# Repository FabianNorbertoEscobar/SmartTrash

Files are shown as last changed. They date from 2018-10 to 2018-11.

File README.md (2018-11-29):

# SMART TRASH

Proyecto SOA UNLaM 2C2018 Miércoles

## Sistemas Operativos Avanzados

### Integrantes del equipo

* Fabián Norberto Escobar ([FabianNorbertoEscobar](https://github.com/FabianNorbertoEscobar))<br>
* Ezequiel Luis Tejerina ([EzequielTejerina](https://github.com/EzequielTejerina))<br>
* Emmanuel Estigarribia ([emmanuel-estigarribia](https://github.com/emmanuel-estigarribia))<br>
* Cristian Vera ([CristianGVera](https://github.com/CristianGVera))<br>
* Martín Ferrarese ([ferrafmz](https://github.com/ferrafmz))<br>

### Sinopsis

Smart Trash es una papelera inteligente que permite arrojar papeles para mantener ordenado y limpio nuestro ambiente, ya sea en el ámbito laboral, de estudio o simplemente en el hogar, con la facilidad de no tener que abrir el tacho ni levantarse del asiento ya que este se abrirá automáticamente cuando detecte que se lo utilice. Esto nos motivó mucho ya que nos suele ocurrir que estamos ocupados realizando otras tareas y ante la necesidad de tirarlos y el tener que evaluar suspender por un momento nuestras actividades, suele optarse por no tirar los bollos de papel y simplemente ir colocándolos a un costado hasta que se forme una montaña de papel o hasta la próxima vez que tengamos que levantarnos y pasar cerca del cesto para poder arrojarlos.

Ya que esta idea ya fue implementada anteriormente, decidimos agregar algunas funcionalidades para distinguirla como información del estado de llenado del tacho con alertas de luces y sonido, y control de la luminosidad de la habitación en la que se encuentre. Además, se brinda la posibilidad de comunicación con una aplicación mobile para Android desde la cual se puede abrir y cerrar la papelera sin la necesidad de estar tan cerca del tacho para que pueda detectar que se desea usarlo. A modo de entretenimiento se ofrece la emisión de una simpática melodía como lo es la Marcha Imperial de Star Wars para distenderse por unos instantes y un modo que llamamos Tacho Loco en que la tapa abre y cierra el tacho rápidamente y de forma indeterminada, y también se puede cambiar a amarillo la luz del led RGB.

## Hardware utilizado
    
### Sistema embebido Arduino
1 placa de prototipado Arduino Uno<br>
1 cable USB puerto serial Arduino Uno 30cm<br>
1 mini Protoboard 830 puntos<br>
1 kit de jumpers con sockets<br>
1 tira de headers macho-macho<br>
6 resistores de 220Ω 5%<br>
1 resistor de 1KΩ 5%<br>
1 módulo Bluetooth HC06<br>
1 LED rojo 5mm<br>
1 LED verde 5mm<br>
1 LED azul 5mm<br>
1 módulo LED RGB<br>
1 pulsador Tact Switch 6mm x 6mm x 5mm<br>
1 micro servo motor Tower Pro Sg90 1.2kg<br>
1 Piezo Buzzer activo 5v<br>
1 fotorresistor Ldr 5mm<br>
2 sensor PIR HC Sr501<br>
1 sensor IR Pcb A0106<br>
1 papelera<br>
1 fuente transformador 9v 1a<br>

### Aplicación Android
Smartphones con sistema operativo Android (para probar la app)<br>
Sensor de proximidad<br>
Acelerómetro<br>
Giroscopio<br>

## Software utilizado

IDE Arduino Genuino 1.8.7 (para el desarrollo del sistema embebido para la placa Arduino Uno)<br>
IDE Android Studio 3.2.1 (para el desarrollo de la aplicación mobile para Android)<br>
Android SDK 28.0.1 (software development kit para Android)<br>
ISO Android 4.0.3 Ice Cream Sandwich (para la simulación de la aplicación mobile para Android)<br>
Tinkercad Autodesk 2018 (para la simulación previa implementación del sistema embebido Arduino)<br>

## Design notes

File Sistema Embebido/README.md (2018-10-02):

# SMART TRASH

Sistema Embebido Arduino

## Sistemas Operativos Avanzados

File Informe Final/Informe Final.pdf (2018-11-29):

### Universidad Nacional de La Matanza

### Departamento de Ingeniería e Investigaciones Tecnológicas Ingeniería en Informática

### Sistemas Operativos Avanzados

### Sistemas Embebidos - Arduino y Android

## “Smart Trash”

Segundo Cuatrimestre 2018 - Año 2018

Docentes:
- Lic. Graciela de Luca
- Ing. Waldo Valiente
- Ing. Esteban Carnuccio
- Ing. Mariano Volker
- Ing. Sebastián Barillaro
- Ing. Gerardo Garcia

Integrantes:
- ESCOBAR, Fabián Norberto | DNI 39210915
- ESTIGARRIBIA, Emmanuel | DNI 38531035
- FERRARESE, Martín | DNI 36073729
- TEJERINA, Ezequiel Luis | DNI 39268074
- VERA, Cristian | DNI 33786091

Sistemas Operativos Avanzados | Smart Trash

### Índice

Introducción | 2
Descripción general del sistema | 2
Alcance del sistema | 3
Sistema embebido Arduino | 3
Aplicación Android | 4
Componentes | 4
Software utilizado | 4
Hardware utilizado | 4
Sistema embebido Arduino | 4
Aplicación Android | 5
Circuito | 5
Implementación | 6
Sistema embebido Android | 6
Módulo Bluetooth | 6
PIR | 6
IR | 7
Fotorresistor | 7
Pulsador | 7
Piezo Buzzer | 7
LED | 8
RGB LED | 8
Micro Servo Motor | 8
Aplicación Android | 8
Activities | 8
Sensores | 12
Modo de uso | 13
Descripción de componentes | 14
Arduino Uno | 14
Fuente de alimentación | 15
Módulo Bluetooth HC05 | 16
Sensor PIR | 16
Sensor IR | 17
Fotoresistor | 18
Pulsador | 18
Piezo Buzzer | 18
LED | 19
RGB LED | 19
Micro Servo Motor | 20
Diagramas | 21
Diagrama físico | 21
Diagrama lógico | 22
Diagrama funcional | 23
Diagrama de hardware | 24
Diagrama de software | 26
Imágenes del prototipo | 27
Problemas presentados y mejoras a futuro | 31

### Introducción

A lo largo de este informe se explica nuestro proyecto para Sistemas Operativos Avanzados, en el que pudimos experimentar en el mundo de los sistemas embebidos y de las aplicaciones mobile. Nos vimos obligados a alejarnos un poco de lo que veníamos acostumbrados a trabajar, es decir, solo software, para poder dedicarnos también al hardware. Llevamos a cabo el desarrollo completo de un proyecto constituido por dos sistemas desde el surgimiento de una idea que nos motive, el planeamiento, el modelado, la adquisición de los componentes necesarios y el entrenamiento para poder trabajar con aquello que no conocíamos, hasta la puesta en marcha de la idea, la simulación del sistema embebido, la prueba de cada componente, su disposición y su conexión, el armado de la estructura, el desarrollo de los sistemas de software, la comunicación entre ellos y el testeo para comprobar que todo funcione adecuadamente.

Primero se describe en detalle la idea y la motivación por la que la hemos elegido, el objetivo de cada uno de los sistemas y todo lo que abarcan. Luego, contamos cuáles son los componentes que se usaron, mostramos un diagrama del circuito con la conexión dispuesta, aclaramos el uso que se le da a cada uno y adjuntamos una descripción técnica y del funcionamiento de cada elemento. Finalmente, se muestran los diagramas usados para el modelado, se cuentan cuáles son los problemas con los que nos hemos topado y se deja una propuesta de mejora a futuro.

### Descripción general del sistema

Smart Trash es una idea que surge de nuestras ganas de desarrollar un producto que brinde comodidades a las personas. Entre otras ideas, esta fue la que prevaleció ya que fue la que más nos gustó e interesó concretar.

Smart Trash es una papelera inteligente que permite arrojar papeles para mantener ordenado y limpio nuestro ambiente, ya sea en el ámbito laboral, de estudio o simplemente en el hogar, con la facilidad de no tener que abrir el tacho ni levantarse del asiento ya que este se abrirá automáticamente cuando detecte que se lo utilice. Esto nos motivó mucho ya que nos suele ocurrir que estamos ocupados realizando otras tareas y ante la necesidad de tirarlos y el tener que evaluar suspender por un momento nuestras actividades, suele optarse por no tirar los bollos de papel y simplemente ir colocándolos a un costado hasta que se forme una montaña de papel o hasta la próxima vez que tengamos que levantarnos y pasar cerca del cesto para poder arrojarlos.

Ya que esta idea ya fue implementada anteriormente, decidimos agregar algunas funcionalidades para distinguirla como información del estado de llenado del tacho con alertas de luces y sonido, y control de la luminosidad de la habitación en la que se encuentre. Además, se brinda la posibilidad de comunicación con una aplicación mobile para Android desde la cual se puede abrir y cerrar la papelera sin la necesidad de estar tan cerca del tacho para que pueda detectar que se desea usarlo. A modo de entretenimiento, se ofrece la emisión de una simpática melodía como lo es la Marcha Imperial de Star Wars para distenderse por unos instantes, un modo que llamamos Tacho Loco en que la tapa abre y cierra el tacho rápidamente y de forma indeterminada, y también se puede cambiar a amarillo el color del led RGB.

Para su uso, usted debe conectar la papelera a la red eléctrica mediante la ficha de su transformador, o también alimentarlo por cable USB y colocarlo en un lugar que le sea cómodo y que quede de frente al lugar en el que se encuentre para que detecte cuando requiera que se abra. No debe colocar nada sobre la tapa del producto que impida que se abra cuando corresponda incluso atentando contra su integridad. Además, debe contar con un smartphone con sistema operativo Android y por supuesto instalar la aplicación de Smart Trash, para poder usarla cuando usted quiera. Cabe aclarar que debe tener encendido el Bluetooth del dispositivo, de lo contrario, se le pedirá que lo encienda.

### Alcance del sistema

Sistema embebido Arduino

El sistema embebido Arduino es el que provee el funcionamiento de la papelera inteligente. Este sistema reside en la placa de prototipado Arduino con la que cuenta el cesto, la que se encuentra detrás de la papelera, dentro de la cajita.

El tacho enciende los LEDs que se encuentran en su frente dando información acerca del nivel de llenado: el LED verde está encendido mientras el tacho no está lleno, es decir, está vacío o aún tiene lugar disponible, y el LED rojo está encendido cuando el tacho está lleno; ambos LEDs se mantienen encendidos durante el vaciado; el LED azul se enciende cuando el tacho está en modo Bluetooth para ser manejado desde la aplicación Android. El LED transparente se apaga o enciende mostrando diferentes colores de acuerdo a la situación, diferenciando cuando en el ambiente hay mucha luz o poca luz, o cuando se está emitiendo la marcha imperial, o cuando se indica un cambio de color desde la aplicación.

Cuando se agita el celular, la tapa se levanta para que se pueda arrojar un bollo de papel y se baja cuando se vuelve a agitar. Cuando se activa el sensor de proximidad del celular, se inicia el modo Tacho Loco, abriendo y cerrando el tacho sin parar. Y la tapa se mantiene levantada cuando se ordena el vaciado del tacho al ser presionado el pulsador amarillo que se encuentra en el perfil derecho o cuando se indica desde la aplicación.

Adelante y sobre la tapa de la papelera, se encuentran los sensores de proximidad que controlan el comportamiento de la tapa. Adentro, está colocado el sensor IR que se encarga de controlar si el tacho se llena. En el perfil izquierdo, se encuentra el buzzer que emite la marcha imperial y el sonido de alerta indicando que el tacho está lleno. El buzzer también emite un sonido tras ser alimentado para indicar que está disponible para ser utilizado. Por último, en la arista delantera izquierda se encuentra el sensor que capta la luminosidad.

Aplicación Android

La aplicación mobile para Android es el sistema que provee la comunicación del smartphone con la papelera inteligente, la que se establece mediante conexión vía Bluetooth. La app tiene una interfaz muy sencilla para facilidad del usuario. Primero que nada muestra los dispositivos Bluetooth emparejados y ofrece agregar y quitar conexiones. Permite abrir y cerrar el tacho como alternativa a la detección de proximidad, así como permite cambiar el color que se emite en el led RGB, habilitar la marcha imperial y el tacho loco. Hace uso de tres sensores del framework de Android: sensor de proximidad, acelerómetro y giróscopo. En base a sus mediciones, ofrece comandos según si el smartphone es agitado, si es colocado de costado o si su sensor frontal detecta proximidad.

### Componentes

Software utilizado

- IDE Arduino Genuino 1.8.7 (para el desarrollo del sistema embebido para la placa Arduino Uno)
- IDE Android Studio 3.2.1 (para el desarrollo de la aplicación mobile para Android).
- Android SDK 28.0.1 (software development kit para Android)
- ISO Android 4.0.3 Ice Cream Sandwich (para la simulación de la aplicación mobile para Android)
- Tinkercad Autodesk 2018 (para la simulación previa implementación del sistema embebido Arduino)

Hardware utilizado

- Sistema embebido Arduino
- 1 placa de prototipado Arduino Uno
- 1 cable USB puerto serial Arduino Uno 30cm
- 1 mini Protoboard 830 puntos
- 1 kit de jumpers con sockets
- 1 tira de headers macho-macho
- 6 resistores de 220Ω 5%
- 1 resistor de 1KΩ 5%
- 1 módulo Bluetooth HC06
- 1 LED rojo 5mm
- 1 LED verde 5mm
- 1 LED azul 5mm
- 1 módulo LED RGB
- 1 pulsador Tact Switch 6mm x 6mm x 5mm
- 1 micro servo motor Tower Pro Sg90 1.2kg
- 1 Piezo Buzzer activo 5v

- 1 fotorresistor Ldr 5mm
- 2 sensor PIR HC Sr501
- 1 sensor IR Pcb A0106
- 1 papelera
- 1 fuente transformador 9v 1a
- Aplicación Android
- Smartphones con sistema operativo Android (para usar la app)
- Sensor de proximidad
- Acelerómetro
- Giroscopio

### Circuito

El circuito fue diseñado y simulado desde el comienzo usando la aplicación online Tinkercad de Autodesk para asegurarnos de cómo se conectan los componentes y que de esa forma funcionan correctamente. También lo usamos como precaución para no correr el riesgo de quemar ningún elemento y en un principio entrenamos aquí para empezar a entrar en contacto con el mundo Arduino.

El proyecto puede encontrarse en https://www.tinkercad.com/things/dwYeEtnybhy, donde puede ser simulado y copiado para ser modificado si alguien lo desea. Allí también puede verse el código con el que fue programado. El circuito simulado se muestra en la siguiente imagen:

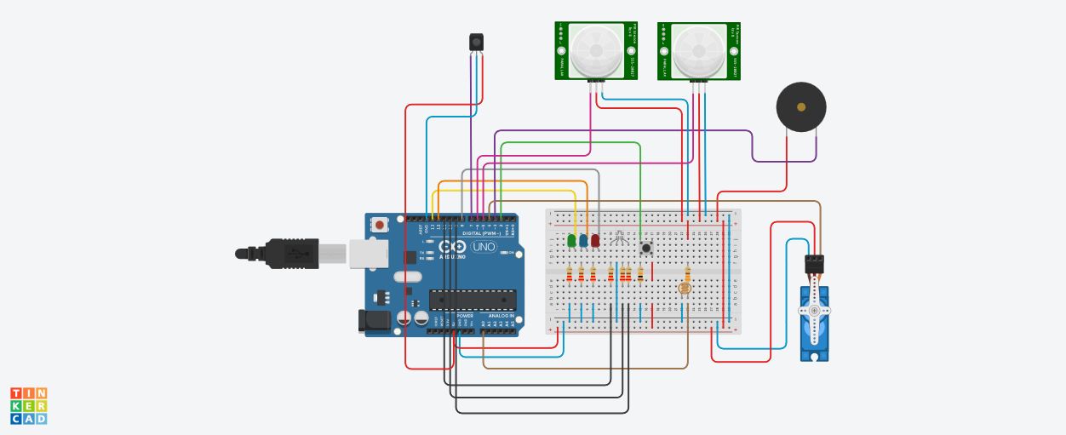
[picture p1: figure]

La única diferencia con la realidad es el uso del módulo Bluetooth el cual no está disponible en este simulador y por lo tanto no pudimos incluir en el diagrama del circuito. El mismo tiene pines positivo y negativo, y dos pines de señal que están conectados a las entradas digitales 0 y 1. El pin Rx del módulo Bluetooth está conectado al pin Tx de la placa Arduino y el pin Tx del módulo Bluetooth está conectado al pin Rx de la placa Arduino.

### Implementación

Sistema embebido - Android

- Módulo Bluetooth

Haciendo uso de la librería “SoftwareSerial.h”, desarrollamos la comunicación del módulo Bluetooth integrado en el Arduino con la aplicación Android. Es una pieza clave en el producto, ya que, a partir de dicha comunicación, se comparten datos que, en base a qué valores tengan, se realizarán distintas acciones (tanto en el sistema embebido Arduino como en la aplicación Android).

Se utilizan las siguientes funciones:
- SoftwareSerial: crea una nueva instancia del objeto SoftwareSerial.
- available: obtiene el número de bytes disponibles para la lectura de un puerto serie software.
- begin: se configura la velocidad en baudios para la comunicación serie.
- read: devuelve un carácter que se recibió en el pin RX del puerto serie de software.
- write: envía los comandos al dispositivo Android.

Básicamente, los datos enviados por la aplicación Android, indican:
- apertura y cierre del tacho.
- modo marcha: emisión de la marcha imperial.
- modo tacho loco: el tacho se abre y cierra.
- cambio de color del led RGB: apagado y color alternativo.
- PIR

Para su implementación, lo único que hicimos es obtener los valores del sensor a través de la función digitalRead. Se le debe configurar la sensibilidad tanto de distancia como de tiempo. Lo configuramos para que tenga un buen alcance para brindar más comodidades a las personas que lo usen.

El sensor PIR viene con un lente de Fresnel que tiene el objetivo de permitir una mayor sensibilidad, pero también amplía el ángulo de detección, por lo que decidimos cubrir parcialmente el lente para que sense solo el rango que nos interese. Uno de los sensores PIR está colocado en el frente del tacho para detectar movimiento adelante y el otro sensor se encuentra en la tapa para que detecte movimiento arriba del tacho.

Si los sensores detectan movimiento, la papelera se abre, y si los sensores no detectan movimiento, la papelera se cierra.

- IR

Para su implementación, de la misma forma que con los sensores PIR, lo único que hicimos es obtener los valores del sensor a través de la función digitalRead. Este sensor se encuentra ubicado dentro del tacho, apuntando desde la cara trasera hacia la cara delantera para cubrir la apertura. Si el sensor detecta una obstrucción dada por un objeto, en este caso papel, entonces se comprende que el tacho está lleno.

- Fotorresistor

El fotorresistor es usado para detectar el nivel de luz que hay en el ambiente y para eso se obtiene el valor de su lectura a través de la función digitalRead. Este sensor se encuentra ubicado en la arista izquierda del frente de la papelera, posición estratégica pensando que el tacho seguramente esté colocado de espaldas a una pared. Allí, la luz va a ser detectada sin inconvenientes.

- Pulsador

El pulsador se utiliza para indicar el vaciamiento del tacho. Para esto, se hace uso de la función digitalRead. Cuando se detecta que fue presionado, de activa el vaciamiento del tacho, por lo que la tapa se queda abierta hasta que se termine de quitar los papeles del interior. Cuando deja de estar presionado el pulsador, la tapa se baja. El pulsador está ubicado en el perfil derecho.

- Piezo Buzzer

El Piezo Buzzer se usa para la emisión de los sonidos. Para reproducir los tonos, se usa la función tone, a la que se indica la frecuencia y la duración del tono, y para no reproducir un tono se usa la función noTone. El speaker se encuentra en el perfil izquierdo.

Por una parte, reproduce la alarma que indica que la papelera está llena, la que consta de dos pitidos que se repetirán hasta que no se vacíe el tacho. Por otra parte, reproduce la marcha imperial de Star Wars, la melodía que elegimos para la funcionalidad de entretenimiento. La marcha imperial está formada por una cantidad mayor de tonos con diversidad de frecuencias y duraciones. Además, se usa para emitir un sonido una vez que el dispositivo está listo para usarse tras haber sido conectado.

Para la correcta formación de la canción de la marcha imperial, es necesaria la utilización de la función delay provista por Arduino para la implementación de las pausas. Y si bien es desalentado su uso debido al parate que implica en el desarrollo de tareas, no queda más que usarla porque de lo contrario la marcha no se puede emitir adecuadamente.

- LED

Los leds son uno de los elementos más sencillos de utilizar ya que se encienden y apagan con la función digitalWrite, variando el parámetro de estado entre HIGH y LOW, según corresponda. Todos los leds se encuentran en el frente de la papelera, en la esquina superior derecha.

El led rojo se enciende cuando el tacho está lleno, el led verde se enciende cuando el tacho está vacío o no está vacío pero aún tiene lugar, ambos están encendidos durante el vaciado y el led azul se enciende cuando el modo Bluetooth está activado.

- RGB LED

Este led RGB tiene un uso similar al de un led común, pero para la formación de un color se da un valor a cada componente con la función digitalWrite, como si se estuviese manejando a tres leds diferentes.

Este led se encuentra en el frente de la papelera, en la esquina superior izquierda. Le asignamos varios usos a este led. Toma distintos colores o se apaga según la ocasión, variando en las siguientes: mucha luz en el ambiente, poca luz en el ambiente, alarma por tacho lleno, marcha Imperial y cambio de color.

- Micro Servo Motor

El servomotor tiene una implementación sencilla. Simplemente se maneja con la función write con la que se indica el ángulo de posición en el que se debe colocar el servo. Está colocado sobre el borde izquierdo del perfil izquierdo del tacho, pegado a la bisagra de la tapa. Solamente se usan dos posiciones: 180 grados para poner el tacho en abierto y 90 grados para poner el tacho en cerrado.

Además interviene obviamente en el modo tacho loco en el que se mueve la tapa sin parar. Para que la apertura y cierre tenga tiempo de realizarse completa, fue necesario el uso de la función delay para generar un retraso

Aplicación Android

- Activities

A continuación, se muestran las activities que forman la aplicación:

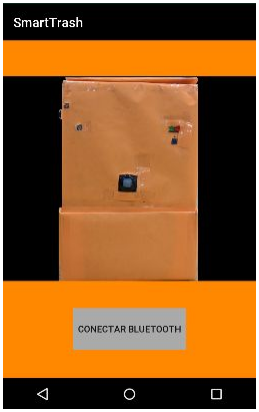
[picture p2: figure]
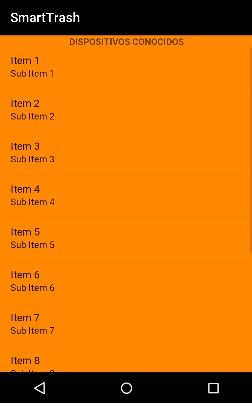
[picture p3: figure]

- Sensores
- Giróscopo

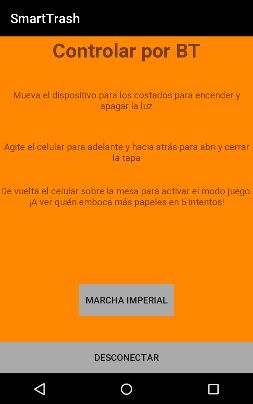
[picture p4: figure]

El giróscopo, giroscopio o gyro, como se conoce en inglés, mide la velocidad de rotación del dispositivo alrededor de los ejes x , y, y z, y sus propiedades se resumen en esta tabla:

Este sensor lo usamos de la siguiente manera:
- cuando se detecta que el smartphone es girado hacia la izquierda, se envía un comando al sistema embebido Arduino para que se encienda el led RGB en su combinación amarilla;

- cuando se detecta que el smartphone es girado hacia la derecha, se envía un comando al sistema embebido Arduino para que se cambie el color del led rgb.
- Acelerómetro

El sensor TYPE_ACCELEROMETER mide la aceleración aplicada al dispositivo y sus propiedades se resumen en esta tabla:

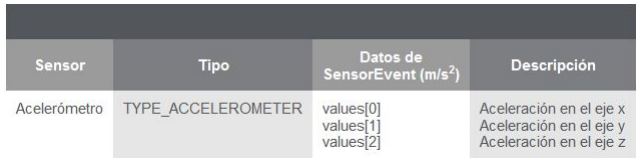
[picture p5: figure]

Este sensor lo usamos de la siguiente manera:
- cuando se detecta que el smartphone es agitado hacia adelante y hacia atrás, se envía un comando al sistema embebido Arduino para que se abra o cierre la papelera, según corresponda, de acuerdo al estado en el que se encuentra la tapa en ese instante.
- Sensor de proximidad

El sensor TYPE_PROXIMITY proporciona la distancia entre el dispositivo y otro objeto y puede por ejemplo usarse para determinar si la persona lo sostiene cerca de su cara al hacer una llamada o simplemente pasa su mano cerca de él; y sus propiedades se resumen en esta tabla:

Este sensor lo usamos de la siguiente manera:
- cuando se detecta que el sensor de proximidad del smartphone está tapado, se envía un comando al sistema embebido Arduino para activar modo juego, el cual abre y cierra la tapa automáticamente unas 5 veces.
- Modo de uso

Es muy sencillo utilizar la app, básicamente pueden realizarse las siguientes:
- previamente, se debe emparejar la papelera con el dispositivo Android por medio de los ajustes del propio sistema.
- abrir la aplicación SmartTrash.
- presionar el botón “Conectar Bluetooth” para ver las papeleras emparejadas.
- presionar la papelera emparejada a la que se desee controlar.
- realizar alguna de las acciones allí mencionada. ¡Hay muchas opciones!
- presionar el botón desconectar la papelera cuando quiera finalizar su uso.

### Descripción de los componentes

- Arduino Uno

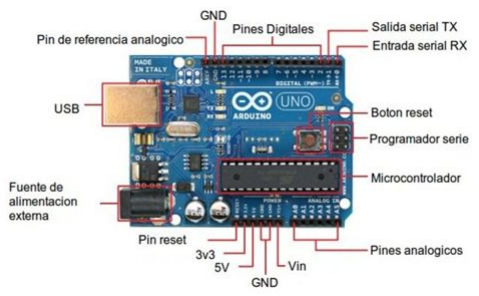
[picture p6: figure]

Arduino es una plataforma de creación de electrónica de código abierto, la cual está basada en hardware y software libre, flexible y fácil de utilizar para los creadores y desarrolladores. Esta plataforma permite crear diferentes tipos de sistemas embebidos a los que la comunidad de creadores puede darles diferentes tipos de uso. Esto es, en gran parte, gracias a la alta compatibilidad con un vasto conjunto de sensores y actuadores de los más variados tipos.

En particular, en nuestro proyecto usamos la placa Arduino UNO R3, la cual es la más documentada de toda la familia de placas Arduino, según la propia página web oficial de Arduino. Esta, al igual que la mayoría, puede ser alimentada de varias formas, con un cable USB conectado al ordenador o con una fuente externa. El lenguaje de programación del microcontrolador está basado en C y C++.

Características técnicas:

Microcontrolador | ATmega328P
Tensión de funcionamiento | 5V
Voltaje de entrada (recomendado) | 7-12V
Voltaje de entrada (límite) | 6-20V
Digital pines I/O | 14 (de los cuales 6 proporcionan una salida PWM)

PWM digital pines I/O | 6
Pines de entrada analógica | 6
Corriente DC por Pin I/O | 20mA
Corriente DC para Pin 3.3V | 60mA
Memoria flash | 32KB ATmega328P de los que 0,5 KB son utilizados por el gestor de arranque.
SRAM | 2KB ATmega328P
EEPROM | 1KB ATmega328P
Velocidad de reloj | 16 MHz
Longitud | 68,6 mm
Anchura | 53,4 mm
Peso | 25 g
- Fuente de alimentación

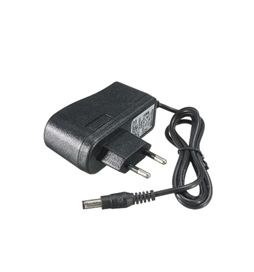
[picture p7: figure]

La fuente de alimentación es el dispositivo que convierte la corriente alterna, en una o varias corrientes continuas, que alimentan los distintos circuitos del aparato electrónico al que se conecta.

En nuestro caso, usamos una fuente de 9v, para alimentar la placa Arduino, junto con los sensores, actuadores, y el módulo bluetooth, para hacer al embebido independiente de tener que estar siempre conectado a una computadora y
poderlo | alimentar | directamente | con | un
tomacorrientes convencional.

- Módulo Bluetooth HC-05

Es el módulo que usamos para conectar el sistema embebido a un celular inalámbricamente. Se configura mediante comandos AT y tiene la posibilidad de hacerlo funcionar tanto en modo maestro como esclavo. Esto quiere decir que además de recibir conexiones desde una PC o celular, también es capaz de generar conexiones hacia otros dispositivos bluetooth.

El módulo Bluetooth HC-05 puede alimentarse
con una tensión de entre 3.3 y 6V (normalmente 5V),
pero los pines TX y RX utilizan niveles de 3,3V por lo

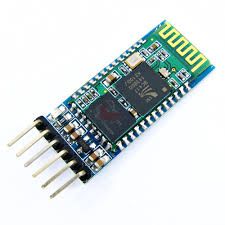
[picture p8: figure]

que no se puede conectar directamente a placas de 5V, sino que hay que usar resistencias para limitar la misma.

- Sensor PIR HC-SR501

Los detectores PIR (Passive Infrared
Receiver) | o | receptor | pasivo | Infrarrojo,
reaccionan ante el calor del cuerpo humano o animales. Estos captan la presencia detectando la diferencia entre el calor emitido por el cuerpo humano y el espacio alrededor. Son llamados pasivos debido a que no emiten radiaciones, sino que solamente las reciben.

Su componente principal son los sensores piroeléctricos. Se trata de un componente electrónico diseñado para detectar cambios en la radiación infrarroja recibida. Generalmente dentro de su encapsulado

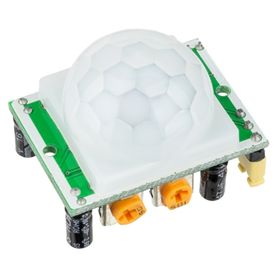
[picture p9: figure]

incorporan un transistor de efecto de campo que amplifica la señal eléctrica que genera cuando se produce dicha variación de radiación recibida. El sensor está dividido en dos mitades. La razón de ello es que se desea detectar movimiento (cambio) y no los niveles promedio de IR. Las dos mitades están cableados de manera que se anulan entre sí. Si uno ve la mitad con más o menos radiación IR que el otro, la salida se moverá a alta o baja.

Además, cuenta con un lente de Fresnel, el cual es un encapsulado semiesférico hecho de polietileno de alta densidad cuyo objetivo es permitir el paso de la radiación infrarroja y concentrar la energía en la superficie de detección del sensor, permitiendo una mayor sensibilidad del dispositivo.

El HC-SR501 permite ajustar el tiempo de disparo de la señal de alarma de movimiento, con un mínimo de 3 seg y un máximo de 5 min. Así mismo, se puede ajustar la distancia de detección, con un mínimo de 3 mts y un máximo de 7 mts.

Especificaciones técnicas:

Voltaje de alimentación | 5 a 12
Consumo promedio | Menor a 1mA
Distancia de detección | 3 a 7 metros
Ángulo de detección | Cono de 110°
Tiempo de inicialización | 1 minuto antes de que inicie su operación normal
Temperatura de operación | -15° a +70° C
- Sensor IR

Formado por un emisor y un receptor IR, es lo que usamos para detectar si el tacho está lleno.

El emisor es un led, que funciona con una longitud de onda de 940nm. Mientras que el receptor es un fotodiodo, un dispositivo que conduce una cantidad de corriente eléctrica proporcional a la cantidad de luz que lo ilumina o incide.

En la implementación establecimos un nivel (la altura donde ubicamos el sensor), y evaluamos si la recepción se corta o no. Este mecanismo nos

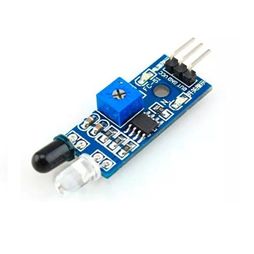
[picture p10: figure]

sirve para contar la cantidad de veces que se tira algo dentro de la papelera, además de la función de detectar si está llena (por haber alcanzado la altura del sensor).

- Fotoresistor (LDR)

El LDR (Light-Dependent Resistor, resistor dependiente de la luz) es un resistor que varía su valor de resistencia eléctrica dependiendo de la cantidad de luz que incide sobre él. Se le llama, también, fotorresistor o fotorresistencia. El valor de resistencia eléctrica de un LDR es bajo cuando hay luz incidiendo en él (en algunos casos puede descender a tan bajo como 50 ohms) y muy alto
cuando está a oscuras (puede ser de varios
megaohms).

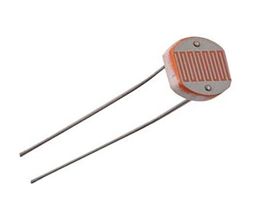
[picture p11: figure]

El uso que le dimos en nuestro proyecto es detectar el nivel de iluminación del ambiente, para prender el led RGB y hacer a la papelera más sencilla de ubicar. Además de poder controlarse desde la aplicación en Android.

- Pulsador

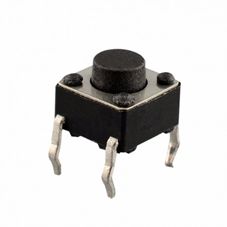
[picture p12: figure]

Un pulsador es básicamente un interruptor con dos estados, presionado o libre. Cuando se presiona, dentro del interruptor, dos cables son unidos, lo que permite a la corriente fluir y envía un estado HIGH a la placa. Cuando se libera, los dos cables son desunidos y corta el flujo de la corriente, significando una estado LOW de señal.

Usamos un pulsador en el proyecto para poder abrir la papelera cuando esta queda bloqueada (al detectar que se llenó), y cerrarla nuevamente para volver a activar los sensores.

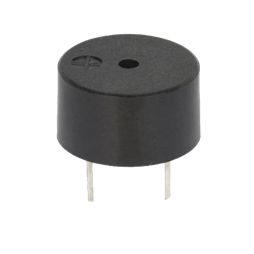
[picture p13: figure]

- Piezo Buzzer

Un buzzer, en español también llamado zumbador, es un transductor electroacústico que produce un sonido o zumbido continuo o intermitente de un mismo tono.

La piezoelectricidad (de ahí el nombre de piezo buzzer) es un fenómeno que ocurre en determinados cristales que, al ser sometidos a tensiones mecánicas, adquieren una polarización eléctrica y aparece una diferencia de potencial y cargas eléctricas en su superficie que generan una tensión eléctrica. Es decir, que son materiales que al someterlos a una tensión eléctrica variable (como una señal PWM) vibran.

Utilizamos el buzzer con diversas funciones, desde alertar que la papelera está llena o que ya ha sido inicializada para usarse, hasta reproducir una melodía en el modo marcha imperial

- LEDs

Un diodo emisor de luz
(también conocido por la sigla LED, del inglés light-emitting diode) es una fuente de luz constituida por un material semiconductor dotado de dos terminales. Se trata de un diodo de unión p-n, que emite luz cuando está activado. Si se aplica una tensión adecuada a los terminales, los electrones se recombinan con los huecos en la región de la unión p-n del dispositivo, liberando energía en forma de fotones.

Usamos 3 leds: rojo, verde y azul. El rojo para indicar que la papelera está llena, el verde para indicar que sigue teniendo espacio, y el azul para indicar conexión con un dispositivo mediante bluetooth.

- LED RGB

Es un tipo de led especial, el cual permite crear combinaciones de los colores primarios en la iluminación (rojo, verde y azul), para mostrar muchos más colores.

Para eso, en el código se envían valores entre 0 y 255 para cada componente de color, representando la intensidad de estos, formando así una gran variedad de colores secundarios y terciarios.

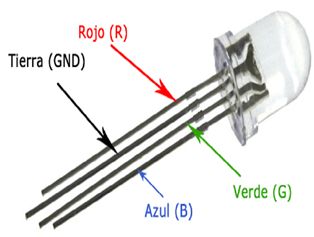
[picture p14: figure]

En nuestro proyecto, el led RGB es usado para dar iluminación a la papelera en caso de baja iluminación del entorno, y para acompañar el modo marcha imperial.

- Micro Servomotor SG-90

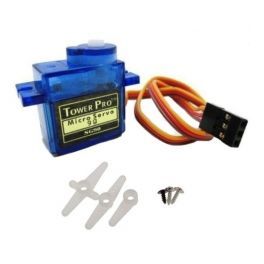
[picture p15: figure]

Un servomotor (también llamado servo) es un dispositivo similar a un motor de corriente continua que tiene la capacidad de ubicarse en cualquier posición dentro de su rango de operación, y mantenerse estable en dicha posición. Tiene incorporado un sistema de regulación que puede ser controlado tanto en velocidad como en posición.

El micro servo SG-90 tiene requerimientos de energía bastante bajos lo que permite alimentarlo con la misma fuente de alimentación que el resto del circuito.

Características técnicas:

Velocidad | 0.10 sec/60° @ 4.8V
Torque | 1.8 Kg-cm @ 4.8V
Voltaje de funcionamiento | 3.0-7.2V
Temperatura de funcionamiento | -30 ℃ a 60 ℃
Ángulo de rotación | 180°
Ancho de pulso | 500-2400 µs

En nuestro proyecto, el micro servo es el que mueve la tapa de la papelera, en función de lo que detecten los sensores, o del comando que el embebido reciba del celular.

### Diagramas

- Diagrama físico

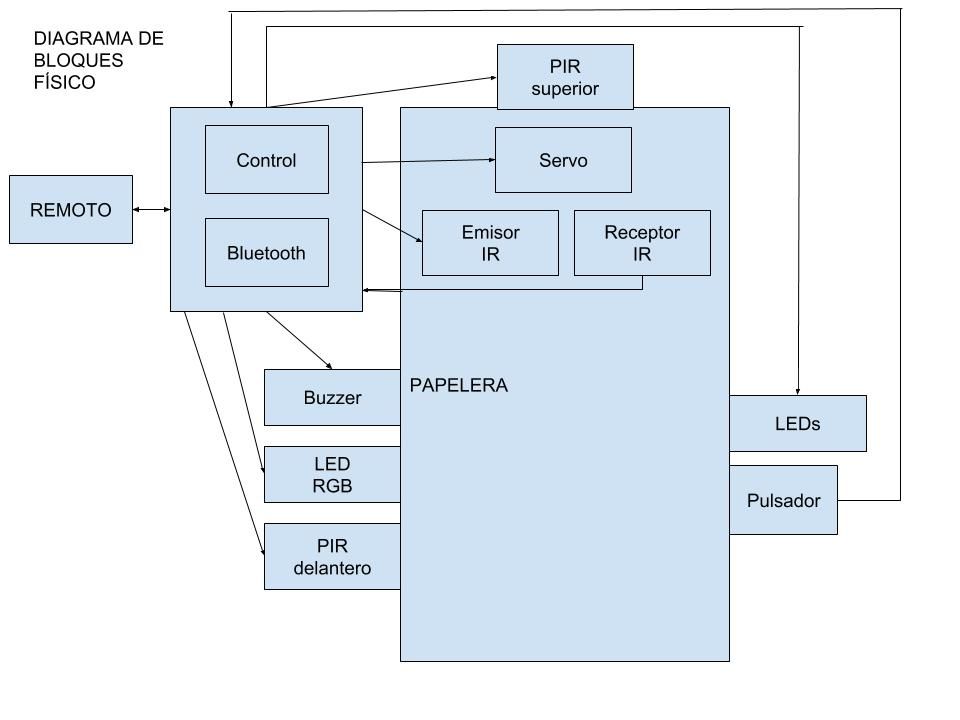
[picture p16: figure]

- Diagrama lógico

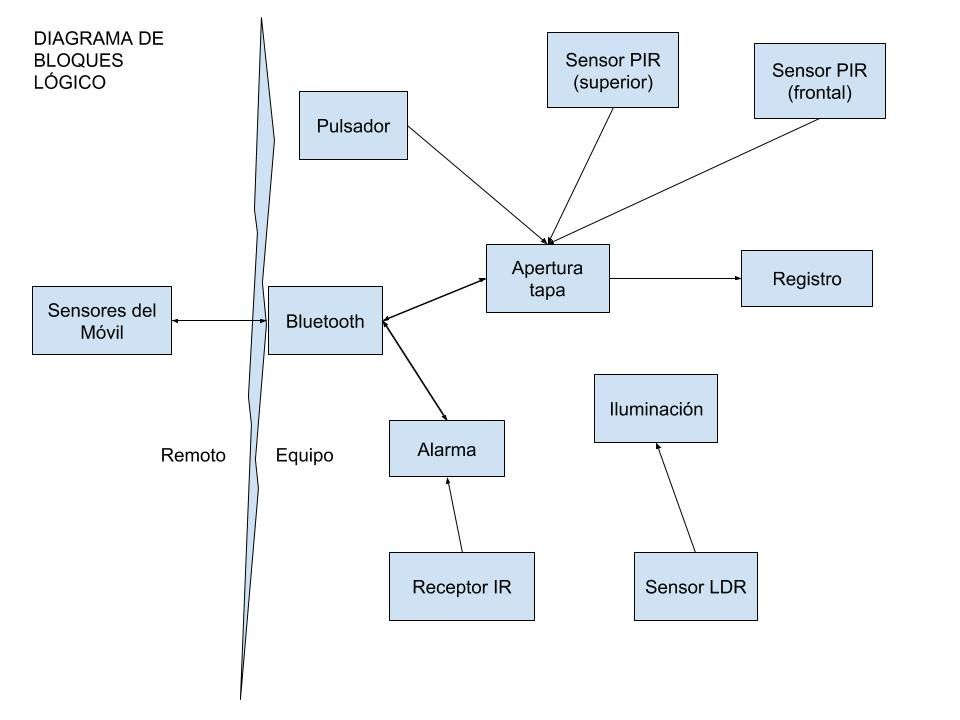
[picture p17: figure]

- Diagrama funcional

- Diagrama de hardware

Vista frontal

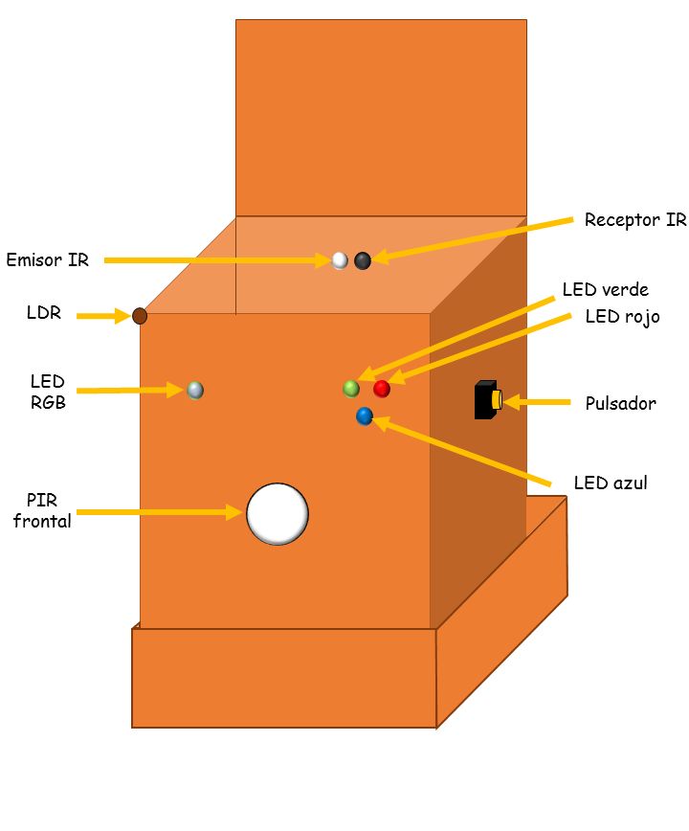
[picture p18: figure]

Vista trasera

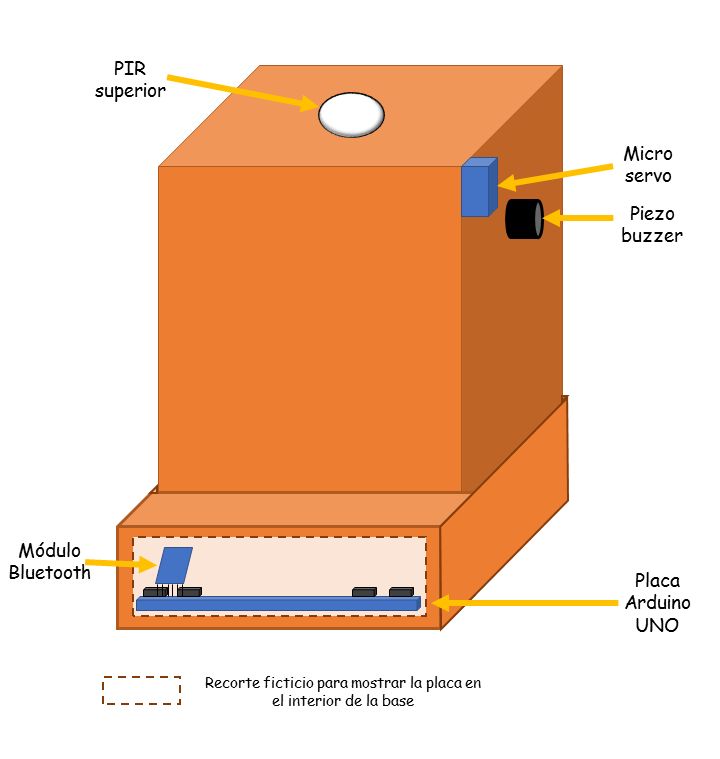
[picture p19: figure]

- Diagrama de software

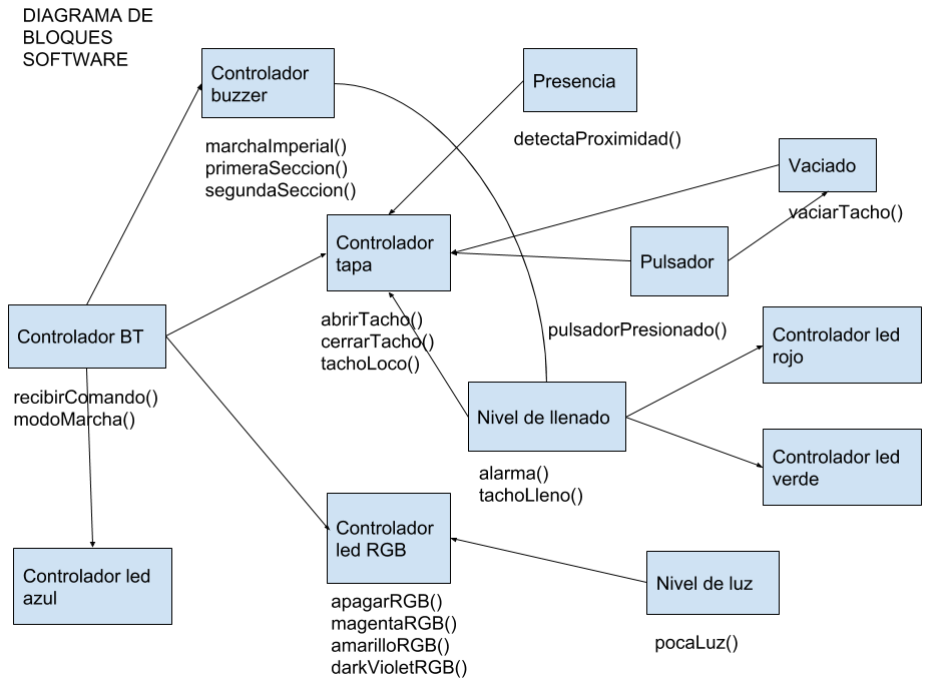
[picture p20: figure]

### Imágenes del prototipo

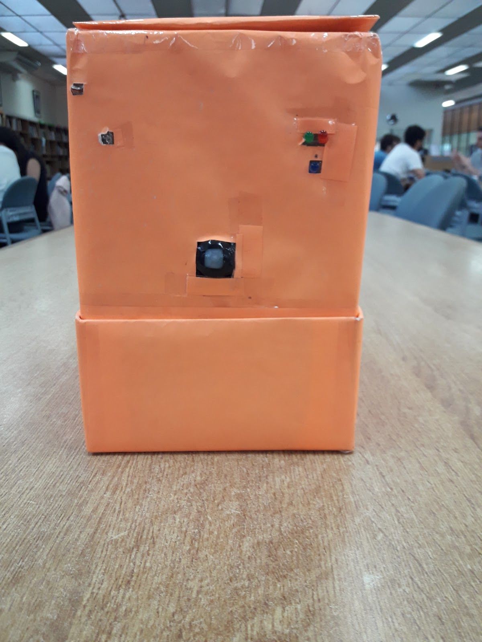
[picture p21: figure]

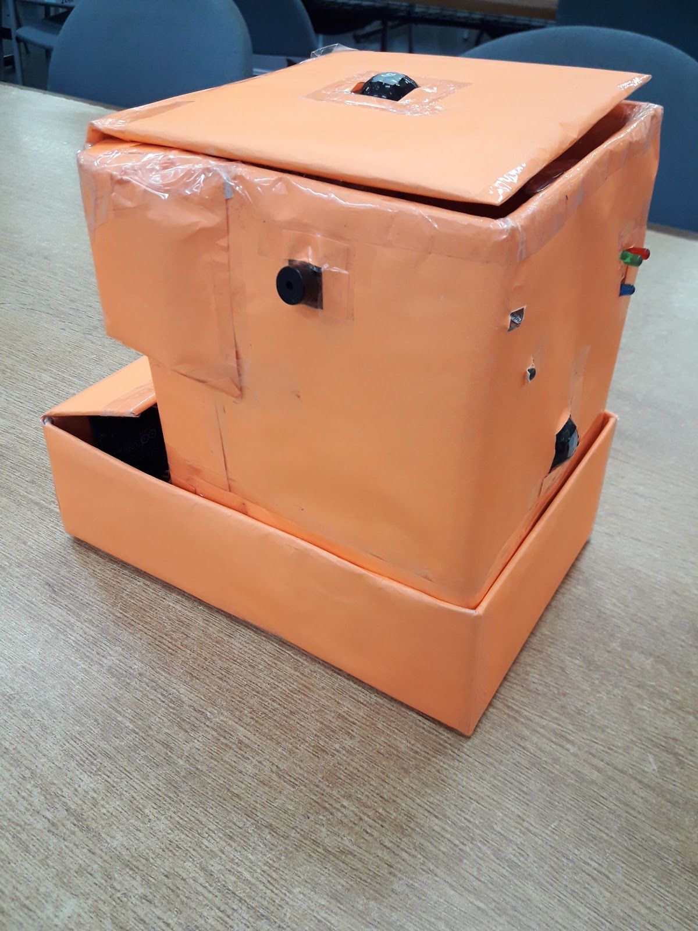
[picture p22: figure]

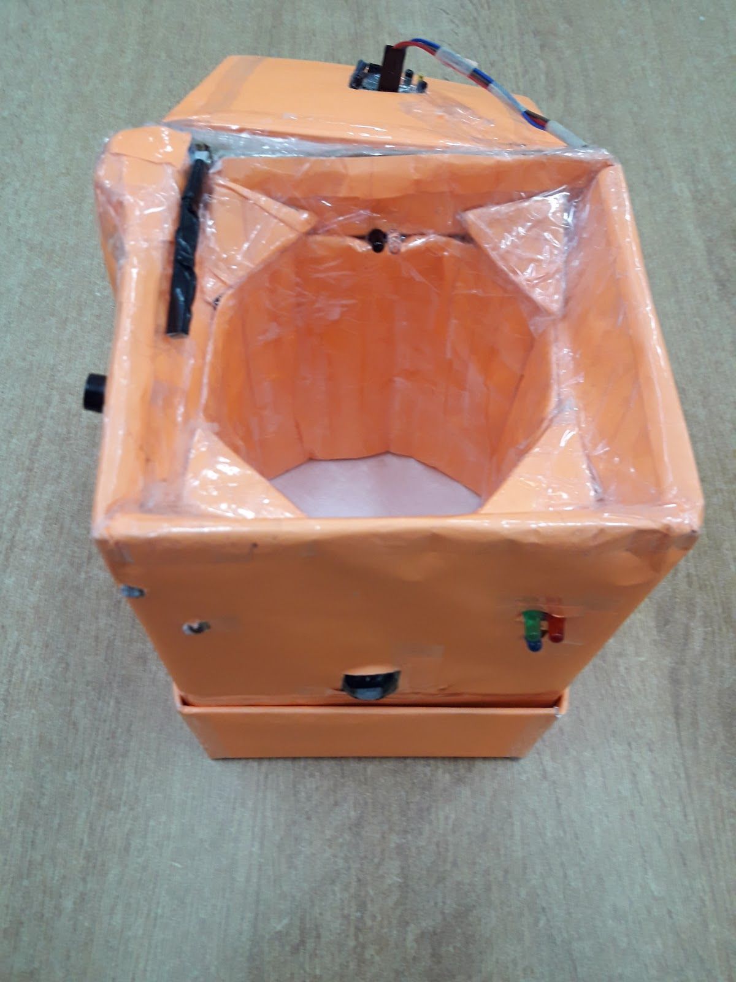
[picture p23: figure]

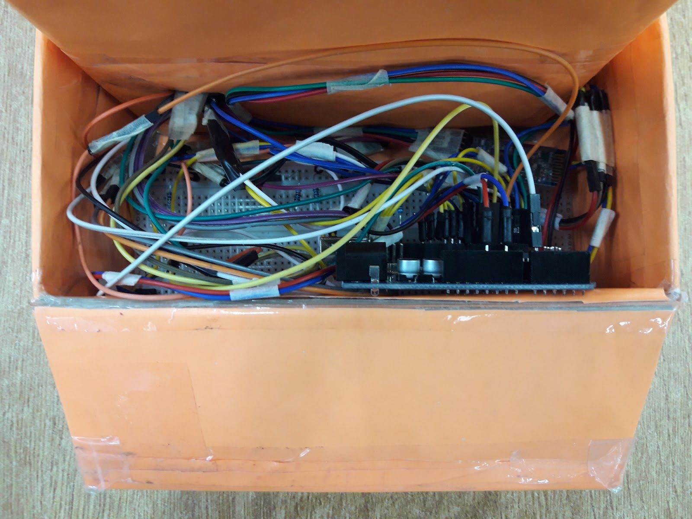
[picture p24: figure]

### Problemas presentados y mejoras a futuro

Los problemas principales o más significativos que tuvimos a la hora de realizar este proyecto fueron: la calibración de los sensores PIR, el uso de los sensores PIR e IR, la colocación y afirmación del servo para que maneje la tapa, y la imposibilidad de paralelismo para desarrollar más de una tarea al mismo tiempo. Una de las cosas que queríamos hacer es que la marcha imperial se emita al mismo tiempo que se activaba el tacho loco. A futuro se podría simular el paralelismo implementando concurrencia.

La mejora principal que se podría agregar es la inclusión de ruedas al tacho para que pueda moverse hasta donde uno se encuentre para solucionar el problema de que se encuentre demasiado lejos para arrojar bollos de papel. Nos gustaría poder conducir el tacho desde la aplicación y que incluso sepa esquivar obstáculos. Este fue un deseo que tuvimos en un principio pero que dejamos de lado debido al poco tiempo con el que contamos para realizar el proyecto.

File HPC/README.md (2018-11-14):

# SMART TRASH

TP de Computación de Altas Prestaciones

## Sistemas Operativos Avanzados

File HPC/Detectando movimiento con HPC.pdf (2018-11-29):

## Papelera con seguimiento inteligente

Escobar Fabián, Estigarribia Emmanuel, Ferrarese Martín, Tejerina Ezequiel, Vera Cristian

Universidad Nacional de La Matanza, Departamento de Ingeniería e Investigaciones Tecnológicas, Florencio Varela 1903 - San Justo, Argentina fabiannorbertoescobar@gmail.com, emmanuelestigarribia@hotmail.com, martin.ferrarese@gmail.com, ezequiel.tejerina95@gmail.com, crygvera@gmail.com

Resumen. El presente trabajo de investigación tiene la finalidad de añadir la funcionalidad de detección de movimiento y seguimiento de personas a nuestro proyecto SmartTrash, mediante el análisis de imágenes con visión artificial, haciendo uso del procesamiento en paralelo.

Palabras clave: HPC, SmartTrash, OpenCV, Detección de movimiento.

### 1 Introducción

El proyecto SmartTrash consta de la implementación de un sistema embebido a una papelera, con el objetivo de hacer más cómodo su uso, proveyéndole de funcionalidades tales como la apertura automática, detección y aviso de llenado, iluminación en base al estado del ambiente, entre otras cosas.

El objetivo de esta investigación es añadir a nuestro embebido la posibilidad de reconocer una persona en movimiento y seguirla en su trayecto, permitiéndole usar la papelera en dondequiera que lo necesite. A dicha funcionalidad la nombramos “Modo limpieza”.

Para esto, haremos uso del modulo GPU integrado en nuestro dispositivo Android, que a través del procesamiento de imágenes e información de forma paralela nos permitirá recolectar los datos necesarios para enviar los comandos a la papelera y que esta comience la persecución.

La GPU, a diferencia de la CPU, tiene como pilar el procesamiento en paralelo de datos¹
, lo cual nos permite sacar ventaja de situaciones donde los algoritmos presentan gran complejidad o que manejan grandes cantidades de datos.

Podemos encontrar ejemplos de detección de movimiento con visión artificial en varios sistemas de seguridad, o sistemas que necesitan hacer un conteo de las personas que entran o salen de algún lugar, entre otras aplicaciones.

### 2 Desarrollo

Para aplicar la funcionalidad propuesta en esta investigación, como primera medida, necesitaremos integrar al tacho un juego de cuatro ruedas con sus correspondientes ejes y motores de corriente continua, y una cámara para obtener información de lo que se encuentra entrente de la papelera, la cual será procesada paralelamente permitiendo la generación de comandos para que nuestra papelera avance siguiendo a la persona detectada. La cámara enviará las imágenes captadas a la placa Arduino, y ésta, a su vez, al dispositivo Android para que sean procesadas.

Una vez activado el modo “Limpieza”, en la aplicación del dispositivo Android, la cámara comenzara el envío de imágenes hacia la placa Arduino.

Para lograr la implementación utilizaremos la librería OpenCV²
, la cual contiene
algoritmos de vision artificial o “computer vision”

3
. Estos algoritmos pueden usarse para reconocimiento facial, identificación de objetos o seguimiento de objetos en movimiento, entre otras cosas.

El proceso de detección de movimiento que se propone implementar está compuesto por 3 tareas: conversión a escala de grises y eliminación de ruido; sustracción entre el segundo y primer plano; y aplicar un umbral a la imagen resultado de la resta.

Dicho proceso se explica en la siguiente sección.

3 Explicación del algoritmo.

Empezaremos leyendo lo que capta la camara del embebido, y guardando cada frame en una matriz Mat.

Teniendo ya cargada previamente la matriz que representa al frame del “fondo” (lo que será la imagen base para encontrar la persona en movimiento), empezamos con el tratamiento de cada frame, pasando por el proceso de las 3 tareas que anteriormente comentábamos.

Conversión a escala de grises y eliminación de ruido.

Antes de realizar ninguna operación con las imágenes, es conveniente convertir a escala de grises. Resulta menos complejo y más óptimo trabajar con este tipo de imágenes. El código de ejemplo está en lenguaje Java.

Por otro lado hay que minimizar el ruido provocado por la propia cámara y por la iluminación. Esto se hace a través de promediar cada píxel con sus vecinos. Se conoce comúnmente como suavizado.

Sustracción entre el segundo plano y el primer plano.

Lo que haremos será restar y obtener los valores absolutos de cada píxel, para no tener ningún número negativo.

Aplicación del umbral.

En esta parte del proceso lo que hacemos es quedarnos con aquellos píxeles que superen un umbral. El objetivo es binarizar la imagen es decir, tener dos posibles valores. Todos aquellos que superen el umbral (significa que no forman parte de la imagen de segundo plano, o fondo) serán píxeles blancos y los que no lo superen serán píxeles negros. Esto nos servirá para seleccionar el objeto en movimiento.

Luego de estos tres pasos, se obtiene una imagen en blanco y negro, que muestra en color negro el fondo, y en blanco el objeto en movimiento.

Esto nos permite luego, en función de la posición de la silueta blanca representando a la persona en movimiento, procesar la dirección hacia dónde se deberá mover el sistema automatizado y enviarlo al sistema embebido para movilizar el sistema de ruedas en la dirección deseada.

La limitación en la primera fase de nuestra investigación es que como la cámara toma una sola imagen como valor de fondo, la persona en movimiento no deberá salirse del plano estático que puede capturar la cámara del embebido, y, como se puede esperar, este solo avanzará en línea recta (siempre que encuentre movimiento enfrente).

### 4 Pruebas que pueden realizarse

En primera instancia, la prueba que puede realizarse es la esperada para su correcto funcionamiento, con la persona caminando medianamente en línea recta, sin salirse del plano que puede captar la cámara del embebido.

Otra prueba posible sería empezar con el camino recto, y desviarse del plano que puede captar la cámara, para confirmar que efectivamente el embebido no se moverá porque no encontrará movimiento o “alguien a quien seguir”.

### 5 Conclusiones

El resultado de la investigación y utilización de OpenCV en nuestro proyecto nos permite añadir una funcionalidad interesante, el seguimiento de una persona, haciendo uso del procesamiento paralelo que es posible gracias a la GPU de un dispositivo móvil.

Como lección aprendida tenemos el aprendizaje y medianamente adentramiento en lo que se conoce como visión artificial por computadora o “Computer Vision”, tecnología que va encontrando cada vez más participación en la actualidad, principalmente en el campo de la videovigilancia.

En un futuro, lo que quisiéramos agregar al proyecto es la capacidad de reconocer movimiento haciendo un uso no estático de la cámara del embebido, lo que supone considerar muchos más factores que los que cubre esta investigación.

### 6 Referencias

1. John D. Owens, Mike Houston, David Luebke, Simon Green, John E. Stone, y James C. Phillips, "GPU Computing" (2008), p. 879-899, Proveniente de IEEE.
https://ieeexplore.ieee.org/abstract/document/4490127
2. Kari Pulli, Anatoly Baksheev, Kirill Kornyakov, Victor Eruhimov. “Real-time computer vision with OpenCV” (2012). https://dl.acm.org/citation.cfm?id=2184337
3. R. Szeliski. Computer Vision: Algorithms and Applications. Springer (2011). https://books.google.com.ar/books?id=bXzAlkODwa8C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 (https://books.google.com.ar/books?id=bXzAlkODwa8C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)

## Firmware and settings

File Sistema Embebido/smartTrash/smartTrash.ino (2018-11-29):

#include<Servo.h>
#include<SoftwareSerial.h>

//pines
byte ledVerde = 13; // tacho con espacio
byte ledAzul = 12; // tapa abierta
byte ledRojo = 8; // tacho lleno

byte rgbRojo = 11; 
byte rgbAzul = 10; 
byte rgbVerde = 9; // cambio de color según luz del ambiente

byte ir = 7; // adentro (nivel)
byte pir2 = 6; // arriba (proximidad)
byte pir1 = 5; // adelante (proximidad)

byte microServo = 4; // controlador de la tapa
byte piezoBuzzer = 3; // alarma marcha imperial
byte pulsador = 2; // vaciar tacho
byte fotoResistor = A0; // luz del ambiente

byte Rx = 0; // Rx Bluetooth
byte Tx = 1; // Tx Bluetooth

//variables
Servo servo;
SoftwareSerial bluetooth(Rx, Tx);
char comando = 's';
bool flagMuchaLuz = false;
int consultaTachoLleno = 0;
unsigned long milisAct;

//frecuencias de la marcha imperial
const float c = 261.63; // Do (Octava 0)
const float d = 293.66; // Re (Octava 0)
const float e = 329.63; // Mi (Octava 0)
const float f = 349.23; // Fa (Octava 0)
const float g = 392.00; // Sol (Octava 0)
const float gS = 415.30;  // Sol# (Octava 0)
const float a = 440.00; // La (Octava 0)
const float b = 466.16; // La# (Octava 0)
const float cH = 523.25;   // Do (Octava 1)
const float cSH = 554.37;  // Do# (Octava 1)
const float dH = 587.33; // Re (Octava 1)
const float dSH = 622.25; // Re# (Octava 1)
const float eH = 659.26; // Mi (Octava 1)
const float fH = 698.46; // Fa (Octava 1)
const float fSH = 739.99; // Fa# (Octava 1)
const float gH = 783.99;  // Sol (Octava 1)
const float gSH = 830.61; // Sol# (Octava 1)
const float aH = 880.00; // La (Octava 1)

void setup(){
  //modo de los pines
  pinMode(ledVerde, OUTPUT);
  pinMode(ledAzul, OUTPUT);
  pinMode(ledRojo, OUTPUT);
  
  pinMode(rgbRojo, OUTPUT);
  pinMode(rgbVerde, OUTPUT);
  pinMode(rgbAzul, OUTPUT);
  
  pinMode(ir, INPUT);
  pinMode(pir2, INPUT);
  pinMode(pir1, INPUT);
  
  servo.attach(microServo);
  pinMode(piezoBuzzer, OUTPUT);
  pinMode(pulsador, INPUT);

  //inicializar componentes
  Serial.begin(9600);
  //servo.write(180);
  digitalWrite(ledVerde, HIGH);
  bluetooth.begin(38400);
  
  //calibrar pir
  for(int i = 0; i > 30; i++){
    delay(1000);
  }
  delay(50);
  milisAct = 0;
  tone(piezoBuzzer, 440, 300);
  noTone(piezoBuzzer);
  tone(piezoBuzzer, 300, 440);
}

void loop(){
  if(bluetooth.available() > 0){
    comando = bluetooth.read();
    
    if(comando == 'b'){
      digitalWrite(ledAzul, HIGH);
      while(comando != 's'){        
        recibirComandoBT();
        bluetooth.flush();
        if(tachoLleno()){
          alarma();
        }
      }
      digitalWrite(ledAzul, LOW);
    }
  }    
  modoSensores();
}

void modoSensores(){
  if(pulsadorPresionado()){
     vaciarTacho();
  }
  if(!tachoLleno())
  {
    if(detectaProximidad()){
      abrirTacho();
    }
    else
    {
      cerrarTacho();
    }
  }
  else{
    alarma();
  }
  if(!pocaLuz()){
    apagarRGB();
  }else{
    magentaRGB();
  }
}

boolean detectaProximidad(){
  return digitalRead(pir1) == HIGH || digitalRead(pir2)== HIGH;
}

boolean tachoLleno(){  
  if(digitalRead(ir) == HIGH){
    consultaTachoLleno = 0;
    return false;
  }
  else{
    consultaTachoLleno++;
  }
  
  if(consultaTachoLleno == 1){
    milisAct = millis();
  }

  if(millis() - milisAct >= 5000){
    return true;
  }
  else{
    return false;
  }
}

void abrirTacho(){
  servo.write(90);
  delay(600);
}

void cerrarTacho(){
  servo.write(180);
  delay(600);
}

void alarma(){
  cerrarTacho();
  digitalWrite(ledVerde, LOW);
  digitalWrite(ledRojo, HIGH);
  while(!pulsadorPresionado()){
    tone(piezoBuzzer, 440, 300);
    noTone(piezoBuzzer);
    tone(piezoBuzzer, 300, 440);
  }
  vaciarTacho();
}

boolean pulsadorPresionado(){
  return digitalRead(pulsador);
}

void vaciarTacho(){
  digitalWrite(ledVerde, HIGH);    
  digitalWrite(ledRojo, HIGH);
  abrirTacho();
  while(!pulsadorPresionado()){
    Serial.println("vaciando");
  }
  digitalWrite(ledRojo, LOW);
  cerrarTacho();
}

boolean pocaLuz(){
  Serial.println(analogRead(fotoResistor));
  return analogRead(fotoResistor) > 920 && analogRead(fotoResistor) < 1000;
}

void apagarRGB(){
  digitalWrite(rgbRojo, 0);
  digitalWrite(rgbVerde, 0);
  digitalWrite(rgbAzul, 0);
}

void magentaRGB(){
  digitalWrite(rgbRojo, 255);
  digitalWrite(rgbVerde, 0);
  digitalWrite(rgbAzul, 255);
}

void darkvioletRGB(){
  digitalWrite(rgbRojo, 148);
  digitalWrite(rgbVerde, 0);
  digitalWrite(rgbAzul, 211);
}

void amarilloRGB(){
  digitalWrite(rgbRojo, 255);
  digitalWrite(rgbVerde, 255);
  digitalWrite(rgbAzul, 0);
}

void recibirComandoBT(){
  if(bluetooth.available() > 0){
    comando = bluetooth.read();
    switch(comando){
      case 'a':
        abrirTacho();
        break;
      case 'c':
        cerrarTacho();
        break;
      case 'v':
        vaciarTacho();
        break;
      case 'j':
        tachoLoco();
        break;
      case 'm':
        modoMarcha();
        break;
      case 'l':
        amarilloRGB();
        break;
      case 'n':
        apagarRGB();
        break;
    }
  }
}

void modoMarcha(){
  darkvioletRGB();
  marchaImperial();
  apagarRGB();
}

void tachoLoco(){
  for(int i = 0; i < 5; i++){
    abrirTacho();
    delay(600);
    cerrarTacho();
    delay(600);
  }  
}

//MARCHA IMPERIAL------------------------------------
void marchaImperial(){
  primeraSeccion();

  segundaSeccion();

  tono(f, 250);  
  tono(gS, 500);  
  tono(f, 350);  
  tono(a, 125);
  tono(cH, 500);
  tono(a, 375);  
  tono(cH, 125);
  tono(eH, 650);

  delay(500);

  segundaSeccion();

  tono(f, 250);  
  tono(gS, 500);  
  tono(f, 375);  
  tono(cH, 125);
  tono(a, 500);  
  tono(f, 375);  
  tono(cH, 125);
  tono(a, 650);  

  delay(650);
}

void tono(int frecuencia, int duracion){
  tone(piezoBuzzer, frecuencia, duracion);
  delay(duracion);
  noTone(piezoBuzzer);
  delay(50);
}

void primeraSeccion(){
  tono(a, 500);
  tono(a, 500);    
  tono(a, 500);
  tono(f, 350);
  tono(cH, 150);  
  tono(a, 500);
  tono(f, 350);
  tono(cH, 150);
  tono(a, 650);

  delay(500);

  tono(eH, 500);
  tono(eH, 500);
  tono(eH, 500);  
  tono(fH, 350);
  tono(cH, 150);
  tono(gS, 500);
  tono(f, 350);
  tono(cH, 150);
  tono(a, 650);

  delay(500);
}

void segundaSeccion(){
  tono(aH, 500);
  tono(a, 300);
  tono(a, 150);
  tono(aH, 500);
  tono(gSH, 325);
  tono(gH, 175);
  tono(fSH, 125);
  tono(fH, 125);    
  tono(fSH, 250);

  delay(325);

  tono(a, 250);
  tono(dSH, 500);
  tono(dH, 325);  
  tono(cSH, 175);  
  tono(cH, 125);  
  tono(b, 125);  
  tono(cH, 250);  

  delay(350);
}
//FIN MARCHA IMPERIAL

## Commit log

2018-10-13 marcha imperial
    [Smart Trash.brd]
2018-10-20 Codigo arduino con Pir e Ir puestos
2018-10-20 Inicio de proyecto en Android
2018-10-21 avances en arduino y corrección de la conexión del foto resistor
    [Smart Trash.brd]
2018-10-27 bluetooth, modo juego y servo loco
2018-10-27 Agregamos posibles funcionalidades del BT. La cinta aisladora fue clave. Corregimos alarma, vaciarTacho() y sensor de cercania
2018-10-29 Reconoce dispositivos previamente enlazados y está encaminado para enviar mensajes al dispositivo al que se conecte
2018-11-10 Uno los archivos y hago unos cambios. Separo la marcha del servo loco porque juntos no lo vamos a hacer. Cambiaron las letras de los comandos recibidos.
    [Smart Trash.brd]
2018-11-10 Se agregó el uso del sensor de proximidad para android
2018-11-11 Se agrega el control del acelerómetro para detectar la sacudida que abre y cierra el tacho
2018-11-11 Se agrega el control del giroscopo. Con este commit, ya tenemos una version principal de todos los sensores siendo sensados
2018-11-11 Version que gestiona sensores y tiene una interfaz un poco más limpia pero no final. Se le van a agregar activities para tener los controles separados para mostrar más facilmente
2018-11-14 Se agrega documento de investigacion
2018-11-14 muevo lo de hpc a una carpeta aparte así está todo bien organizado
2018-11-14 Se agrega el informe final, versión 1. después le agregamos más cosas
2018-11-14 Se mejora el README.md
2018-11-14 Se agrega el paper de HPC
2018-11-14 Agrego activities que se van a implementar en un futuro
2018-11-15 Codigo embebido con bluetooth y codigo android con funcionamiento de apertura de tapa (acelerometro) y prendido y apago de la funcionalidades bluetooth
    [Smart Trash.brd]
2018-11-18 Version con sensores funcionando. Falta probar bluetooth y sacar delays
2018-11-18 Android no funcional por las pruebas de las interfaces. Problemas con el bluetooth. Arduino con sensores andando, igual que en el master
    [smartTrash.ino]
2018-11-18 Primera versión HPC/cambio de nombre en el archivo
2018-11-19 Se actualiza el informe final
    [Smart Trash.brd]
2018-11-22 Se corrigió la funcionalidad del sensor fotosensible. En Androdi, se acomodaron los controles del tacho. Se opitimizó el modo juego. Falta agregar la funcionalidad de la marcha y seguir con las prueb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
    [smartTrash.ino]
2018-11-22 Se corrigió el código de Android y Arduino por problemas con el merge
    [smartTrash.ino]
2018-11-24 Se actualiza el informe con los últimos cambios que hablamos
2018-11-28 Se actualiza el Informe Final con nuevas imágenes y correción de las acciones de los sensores de Android. Se actualiza la aplicación con una nueva interfaz inicial y se agrega el botón de la marcha i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
2018-11-28 Se sube una nueva versión del Informe con correciones y nuevas interfaces de la app
2018-11-28 Se corrige el informe
    [smartTrash.ino]
2018-11-28 Se corrige esto porque sino no iba a andar
    [smartTrash.ino]
2018-11-28 Corrijo el amarillo
2018-11-29 Se limpia el código para entrega
2018-11-29 Se limpia el código Android y Arduino
2018-11-29 Se corrije el diagrama de software del informe
2018-11-29 Se borra el handler que no usamos
2018-11-29 Se elimina funcionalidad que no se utiliza
2018-11-29 Eliminado el 1 fantasma de la variable
